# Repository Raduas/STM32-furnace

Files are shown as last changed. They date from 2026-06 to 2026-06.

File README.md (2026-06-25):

# STM32 Induction Furnace

A personal project focused on designing and building a resonant H-bridge induction furnace controlled by an STM32 microcontroller.

This was my first larger electronics project and gave me hands-on experience with power electronics, control systems, PCB design, and embedded software development.

The furnace was not completed as a final product, but core functionality was successfully tested. Maximum achieved temperature reached the Curie point.

# Challenges
Learning the fundamentals of power electronics.
Understanding resonant circuits and H-bridge operation.
Designing reliable gate driver circuits.
Managing electrical noise and ground isolation.
Debugging hardware and software interactions.
Developing and tuning control algorithms.

# Lessons Learned

Through this project, I gained practical experience in:

Power electronics design.
Designing power supplies with multiple voltage levels.
STM32 development using STM32CubeIDE.
Implementing control algorithms for an H-bridge inverter.
Applying Ohm's Law and basic circuit analysis in real-world situations.
Reading and understanding component datasheets.
PCB design, including gate driver layout and ground isolation.
Using laboratory equipment such as oscilloscopes and multimeters.
System debugging and troubleshooting.

## PCB Design

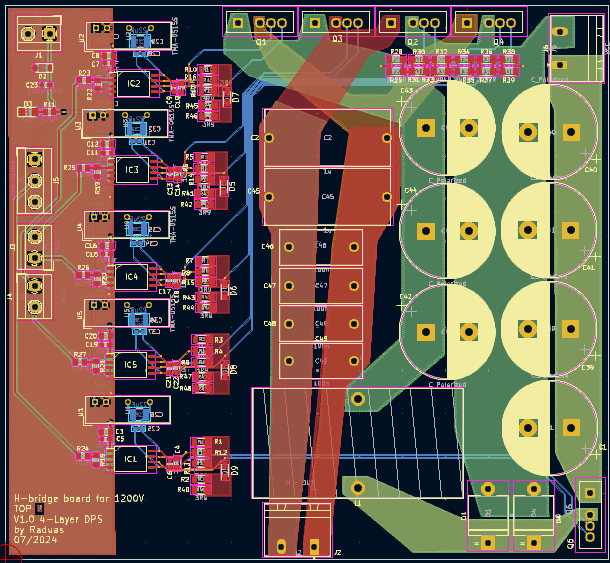
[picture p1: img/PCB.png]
PCB


## Schematic

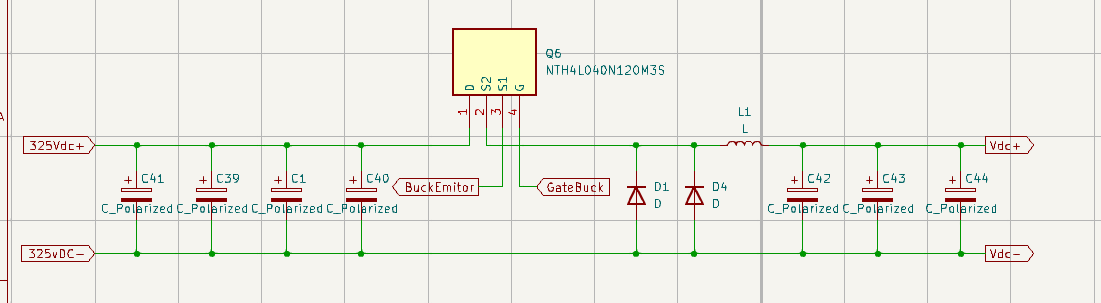
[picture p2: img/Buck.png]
Buck

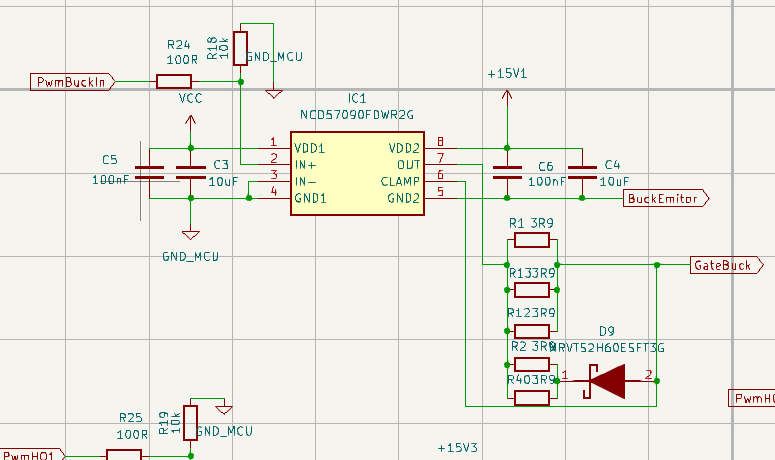
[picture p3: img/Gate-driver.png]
Gate Driver

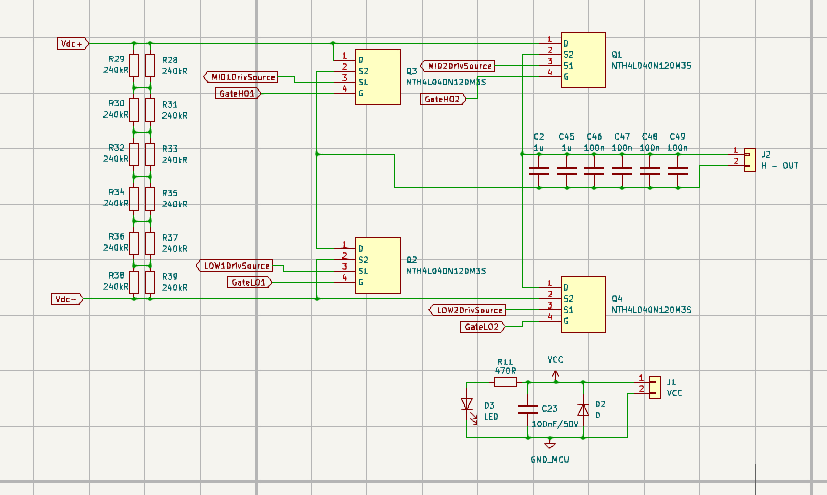
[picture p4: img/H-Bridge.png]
H-Bridge


## Assebled PCB

Assebled PCB

# Future Improvements

If I were to redesign the system today, I would:

Improve thermal management and cooling.
Reconsider the overall system architecture.
Spend more time on mathematical analysis before implementation.
Perform more simulations and design reviews early in development.
Add additional protection features and fault detection mechanisms.
Improve PCB layout to reduce noise and simplify debugging.

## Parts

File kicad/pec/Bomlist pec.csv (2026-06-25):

'Reference' | 'Value' | 'Datasheet' | 'Footprint' | 'Qty' | 'DNP'
'C1,C39,C40,C41,C42,C43,C44' | 'C_Polarized' | '~' | 'Capacitor_THT:CP_Radial_D22.0mm_P10.00mm_SnapIn' | '7' | ''
'C2,C45' | '1u' | '~' | 'Capacitor_THT:C_Rect_L29.0mm_W13.0mm_P27.50mm_MKT' | '2' | ''
'C3,C4,C8,C10,C12,C14,C16,C18,C20,C22' | '10uF' | '~' | 'Capacitor_SMD:C_0805_2012Metric_Pad1.18x1.45mm_HandSolder' | '10' | ''
'C5,C6,C7,C9,C11,C13,C15,C17,C19,C21,C24,C25,C27,C28,C30,C31,C33,C34,C36,C37' | '100nF' | '~' | 'Capacitor_SMD:C_0603_1608Metric_Pad1.08x0.95mm_HandSolder' | '20' | ''
'C23' | '100nF/50V' | '~' | 'Capacitor_SMD:C_0603_1608Metric_Pad1.08x0.95mm_HandSolder' | '1' | ''
'C26,C29,C32,C35,C38' | '22uF' | '~' | 'Capacitor_SMD:C_1210_3225Metric_Pad1.33x2.70mm_HandSolder' | '5' | ''
'C46,C47,C48,C49' | '100n' | '~' | 'Capacitor_THT:C_Rect_L19.0mm_W8.0mm_P15.00mm_MKS4' | '4' | ''
'D1,D2,D4' | 'D' | '~' | '-- mixed values --' | '3' | ''
'D3' | 'LED' | '~' | 'LED_SMD:LED_1206_3216Metric_Pad1.42x1.75mm_HandSolder' | '1' | ''
'D5,D6,D7,D8,D9' | 'NRVTS2H60ESFT3G' | 'https://www.onsemi.com/pub/Collateral/NRVTS2H60ESF-D.PDF' | 'SODFL3616X98N' | '5' | ''
'IC1,IC2,IC3,IC4,IC5' | 'NCD57090FDWR2G' | 'https://www.onsemi.com/pub/Collateral/NCD57090A-D.PDF' | 'SOIC127P1031X265-8N' | '5' | ''
'J1,J3,J4,J6' | 'VCC' | '~' | '-- mixed values --' | '4' | ''
'J2' | 'H - OUT' | '~' | 'Connector_Phoenix_GMSTB:PhoenixContact_GMSTBA_2,5_2-G-7,62_1x02_P7.62mm_Horizontal' | '1' | ''
'J5' | 'Conn_01x03' | '~' | 'TerminalBlock_MetzConnect:TerminalBlock_MetzConnect_Type055_RT01503HDWU_1x03_P5.00mm_Horizontal' | '1' | ''
'L1' | 'L' | '~' | 'Inductor_THT:L_Toroid_Vertical_L48.8mm_W25.4mm_P20.80mm_Vishay_TJ8' | '1' | ''
'Q1,Q2,Q3,Q4,Q6' | 'NTH4L040N120M3S' | 'https://www.onsemi.com/pub/Collateral/NTH4L040N120M3S-D.PDF' | 'NTH4L040N120M3S' | '5' | ''
'R1,R2,R3,R4,R5,R6,R7,R8,R9,R10,R12,R13,R14,R15,R16,R17,R40,R41,R42,R43,R44,R45,R46,R47,R48' | '3R9' | '~' | 'Resistor_SMD:R_1206_3216Metric_Pad1.30x1.75mm_HandSolder' | '25' | ''
'R11' | '470R' | '~' | 'Resistor_SMD:R_0805_2012Metric_Pad1.20x1.40mm_HandSolder' | '1' | ''
'R18,R19,R20,R21,R22' | '10k' | '~' | 'Resistor_SMD:R_0805_2012Metric_Pad1.20x1.40mm_HandSolder' | '5' | ''
'R23,R24,R25,R26,R27' | '100R' | '~' | 'Resistor_SMD:R_0805_2012Metric_Pad1.20x1.40mm_HandSolder' | '5' | ''
'R28,R29,R30,R31,R32,R33,R34,R35,R36,R37,R38,R39' | '240kR' | '~' | 'Resistor_SMD:R_1206_3216Metric_Pad1.30x1.75mm_HandSolder' | '12' | ''
'U1,U2,U3,U4,U5' | 'TMA-0515S' | 'https://www.tracopower.com/products/tma.pdf' | 'Converter_DCDC:Converter_DCDC_TRACO_TMA-05xxS_12xxS_Single_THT' | '5' | ''

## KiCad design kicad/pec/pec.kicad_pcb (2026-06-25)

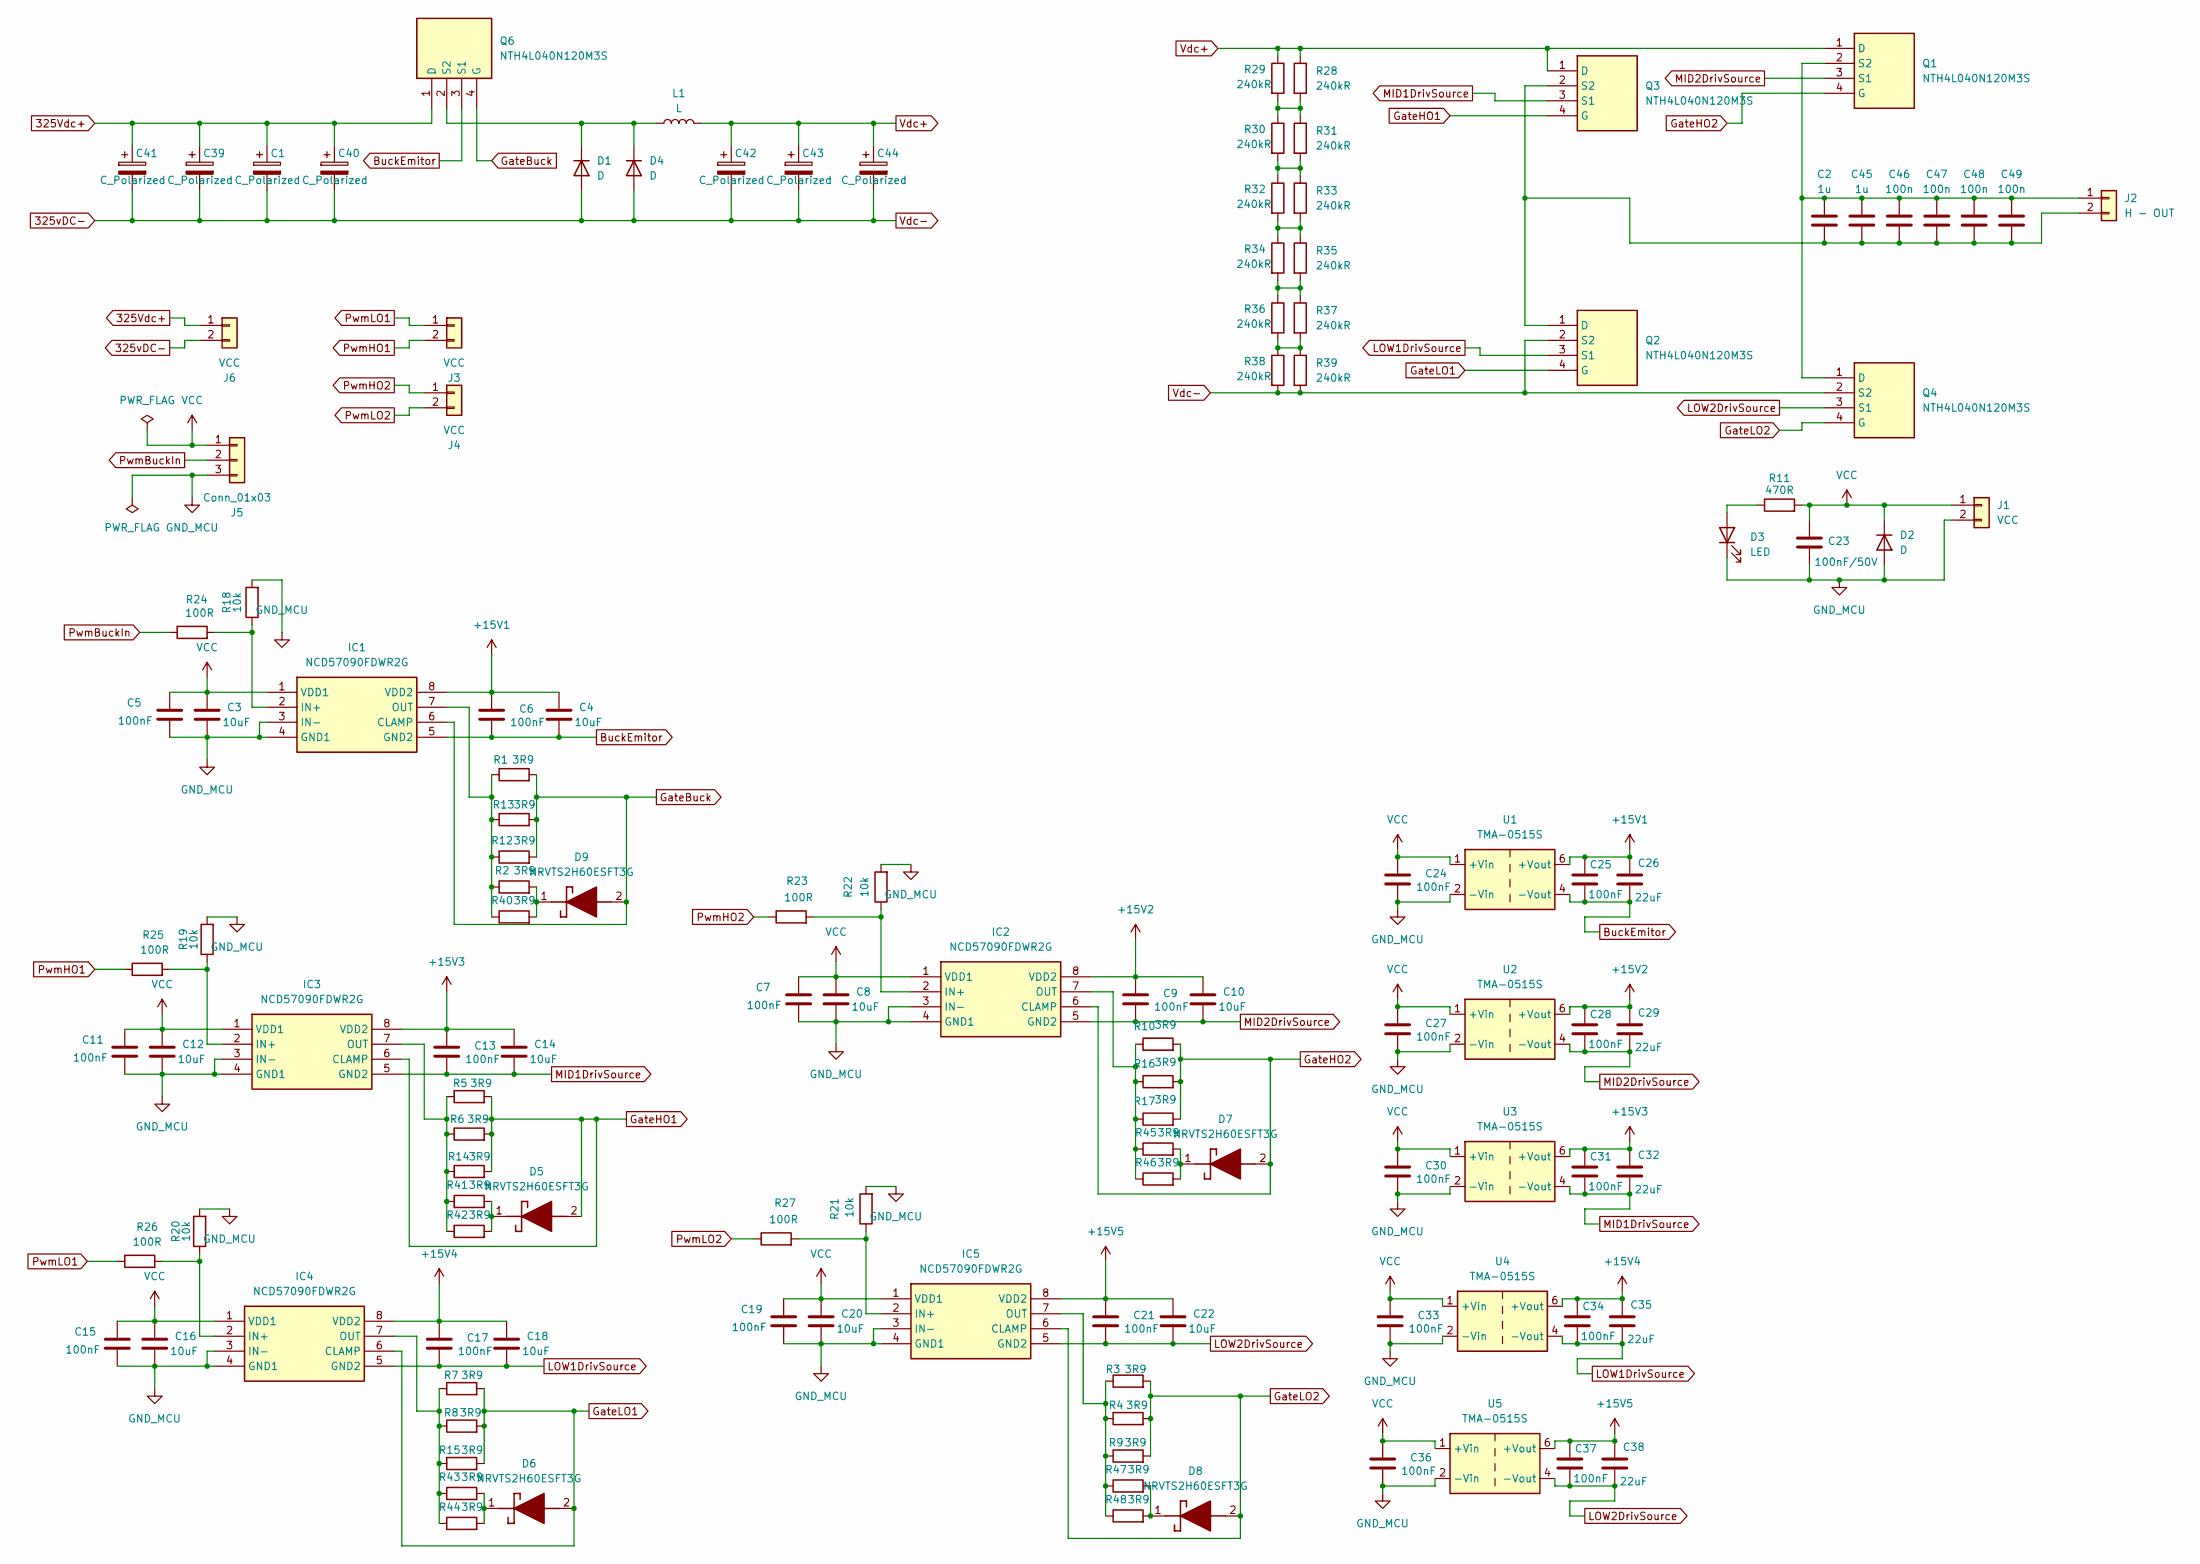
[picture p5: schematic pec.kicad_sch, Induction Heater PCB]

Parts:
C1, C39, C40, C41, C42, C43, C44: C_Polarized; CP_Radial_D22.0mm_P10.00mm_SnapIn
C2, C45: 1u; C_Rect_L29.0mm_W13.0mm_P27.50mm_MKT
C3, C4, C8, C10, C12, C14, C16, C18, C20, C22: 10uF; C_0805_2012Metric_Pad1.18x1.45mm_HandSolder
C5, C6, C7, C9, C11, C13, C15, C17, C19, C21, C24, C25, C27, C28, C30, C31, C33, C34, C36, C37: 100nF; C_0603_1608Metric_Pad1.08x0.95mm_HandSolder
C23: 100nF/50V; C_0603_1608Metric_Pad1.08x0.95mm_HandSolder
C26, C29, C32, C35, C38: 22uF; C_1210_3225Metric_Pad1.33x2.70mm_HandSolder
C46, C47, C48, C49: 100n; C_Rect_L19.0mm_W8.0mm_P15.00mm_MKS4
D1, D4: D; D_P600_R-6_P12.70mm_Horizontal
D2: D; D_SOD-123
D3: LED; LED_1206_3216Metric_Pad1.42x1.75mm_HandSolder
D5, D6, D7, D8, D9: NRVTS2H60ESFT3G; SODFL3616X98N; Manufacturer_Part_Number NRVTS2H60ESFT3G; Mouser Part Number 863-NRVTS2H60ESFT3G
IC1, IC2, IC3, IC4, IC5: NCD57090FDWR2G; SOIC127P1031X265-8N; Manufacturer_Part_Number NCD57090FDWR2G; Mouser Part Number 863-NCD57090FDWR2G
J1, J3, J4: VCC; TerminalBlock_MetzConnect_Type055_RT01502HDWU_1x02_P5.00mm_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
J2: H - OUT; PhoenixContact_GMSTBA_2,5_2-G-7,62_1x02_P7.62mm_Horizontal
J5: Conn_01x03; TerminalBlock_MetzConnect_Type055_RT01503HDWU_1x03_P5.00mm_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
J6: VCC; PhoenixContact_GMSTBA_2,5_2-G-7,62_1x02_P7.62mm_Horizontal
L1: L; L_Toroid_Vertical_L48.8mm_W25.4mm_P20.80mm_Vishay_TJ8
Q1, Q2, Q3, Q4, Q6: NTH4L040N120M3S; Manufacturer_Part_Number NTH4L040N120M3S; Mouser Part Number 863-NTH4L040N120M3S
R1, R2, R3, R4, R5, R6, R7, R8, R9, R10, R12, R13, R14, R15, R16, R17, R40, R41, R42, R43, R44, R45, R46, R47, R48: 3R9; R_1206_3216Metric_Pad1.30x1.75mm_HandSolder
R11: 470R; R_0805_2012Metric_Pad1.20x1.40mm_HandSolder
R18, R19, R20, R21, R22: 10k; R_0805_2012Metric_Pad1.20x1.40mm_HandSolder
R23, R24, R25, R26, R27: 100R; R_0805_2012Metric_Pad1.20x1.40mm_HandSolder
R28, R29, R30, R31, R32, R33, R34, R35, R36, R37, R38, R39: 240kR; R_1206_3216Metric_Pad1.30x1.75mm_HandSolder
U1, U2, U3, U4, U5: TMA-0515S; Converter_DCDC_TRACO_TMA-05xxS_12xxS_Single_THT

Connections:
325Vdc+: C1.1, C39.1, C40.1, C41.1, J6.1, Q6.1 (D)
325vDC-: C1.2, C39.2, C40.2, C41.2, C42.2, C43.2, C44.2, D1.2 (A), D4.2 (A), J6.2, Q2.2 (S2), Q4.2 (S2), R38.2, R39.2
+15V1: C4.2, C6.2, C25.2, C26.2, IC1.8 (VDD2), U1.6 (+Vout)
+15V2: C9.2, C10.2, C28.2, C29.2, IC2.8 (VDD2), U2.6 (+Vout)
+15V3: C13.2, C14.2, C31.2, C32.2, IC3.8 (VDD2), U3.6 (+Vout)
+15V4: C17.2, C18.2, C34.2, C35.2, IC4.8 (VDD2), U4.6 (+Vout)
+15V5: C21.2, C22.2, C37.2, C38.2, IC5.8 (VDD2), U5.6 (+Vout)
BuckEmitor: C4.1, C6.1, C25.1, C26.1, IC1.5 (GND2), Q6.3 (S1), U1.4 (-Vout)
GND_MCU: C3.1, C5.1, C7.1, C8.1, C11.1, C12.1, C15.1, C16.1, C19.1, C20.1, C23.1, C24.1, C27.1, C30.1, C33.1, C36.1, D2.2 (A), D3.1 (K), IC1.3 (IN-), IC1.4 (GND1), IC2.3 (IN-), IC2.4 (GND1), IC3.3 (IN-), IC3.4 (GND1), IC4.3 (IN-), IC4.4 (GND1), IC5.3 (IN-), IC5.4 (GND1), J1.2, J5.3, R18.2, R19.2, R20.2, R21.2, R22.2, U1.2 (-Vin), U2.2 (-Vin), U3.2 (-Vin), U4.2 (-Vin), U5.2 (-Vin)
GateBuck: D9.2 (A), IC1.6 (CLAMP), Q6.4 (G), R1.2, R12.2, R13.2
GateHO1: D5.2 (A), IC3.6 (CLAMP), Q3.4 (G), R5.2, R6.2, R14.2
GateHO2: D7.2 (A), IC2.6 (CLAMP), Q1.4 (G), R10.2, R16.2, R17.2
GateLO1: D6.2 (A), IC4.6 (CLAMP), Q2.4 (G), R7.2, R8.2, R15.2
GateLO2: D8.2 (A), IC5.6 (CLAMP), Q4.4 (G), R3.2, R4.2, R9.2
LOW1DrivSource: C17.1, C18.1, C34.1, C35.1, IC4.5 (GND2), Q2.3 (S1), U4.4 (-Vout)
LOW2DrivSource: C21.1, C22.1, C37.1, C38.1, IC5.5 (GND2), Q4.3 (S1), U5.4 (-Vout)
MID1DrivSource: C13.1, C14.1, C31.1, C32.1, IC3.5 (GND2), Q3.3 (S1), U3.4 (-Vout)
MID2DrivSource: C9.1, C10.1, C28.1, C29.1, IC2.5 (GND2), Q1.3 (S1), U2.4 (-Vout)
unnamed: D1.1 (K), D4.1 (K), L1.1, Q6.2 (S2)
unnamed: D3.2 (A), R11.1
unnamed: D5.1 (K), R41.2, R42.2
unnamed: D6.1 (K), R43.2, R44.2
unnamed: D7.1 (K), R45.2, R46.2
unnamed: D8.1 (K), R47.2, R48.2
unnamed: D9.1 (K), R2.2, R40.2
unnamed: IC1.2 (IN+), R18.1, R24.2
unnamed: IC1.7 (OUT), R1.1, R2.1, R12.1, R13.1, R40.1
unnamed: IC2.2 (IN+), R22.1, R23.2
unnamed: IC2.7 (OUT), R10.1, R16.1, R17.1, R45.1, R46.1
unnamed: IC3.2 (IN+), R19.1, R25.2
unnamed: IC3.7 (OUT), R5.1, R6.1, R14.1, R41.1, R42.1
unnamed: IC4.2 (IN+), R20.1, R26.2
unnamed: IC4.7 (OUT), R7.1, R8.1, R15.1, R43.1, R44.1
unnamed: IC5.2 (IN+), R21.1, R27.2
unnamed: IC5.7 (OUT), R3.1, R4.1, R9.1, R47.1, R48.1
unnamed: C2.2, C45.2, C46.2, C47.2, C48.2, C49.2, J2.1, Q1.2 (S2), Q4.1 (D)
unnamed: C2.1, C45.1, C46.1, C47.1, C48.1, C49.1, J2.2, Q2.1 (D), Q3.2 (S2)
unnamed: R28.2, R29.2, R30.1, R31.1
unnamed: R30.2, R31.2, R32.1, R33.1
unnamed: R32.2, R33.2, R34.1, R35.1
unnamed: R34.2, R35.2, R36.1, R37.1
unnamed: R36.2, R37.2, R38.1, R39.1
PwmBuckIn: J5.2, R24.1
PwmHO1: J3.2, R25.1
PwmHO2: J4.1, R23.1
PwmLO1: J3.1, R26.1
PwmLO2: J4.2, R27.1
VCC: C3.2, C5.2, C7.2, C8.2, C11.2, C12.2, C15.2, C16.2, C19.2, C20.2, C23.2, C24.2, C27.2, C30.2, C33.2, C36.2, D2.1 (K), IC1.1 (VDD1), IC2.1 (VDD1), IC3.1 (VDD1), IC4.1 (VDD1), IC5.1 (VDD1), J1.1, J5.1, R11.2, U1.1 (+Vin), U2.1 (+Vin), U3.1 (+Vin), U4.1 (+Vin), U5.1 (+Vin)
Vdc+: C42.1, C43.1, C44.1, L1.2, Q1.1 (D), Q3.1 (D), R28.1, R29.1

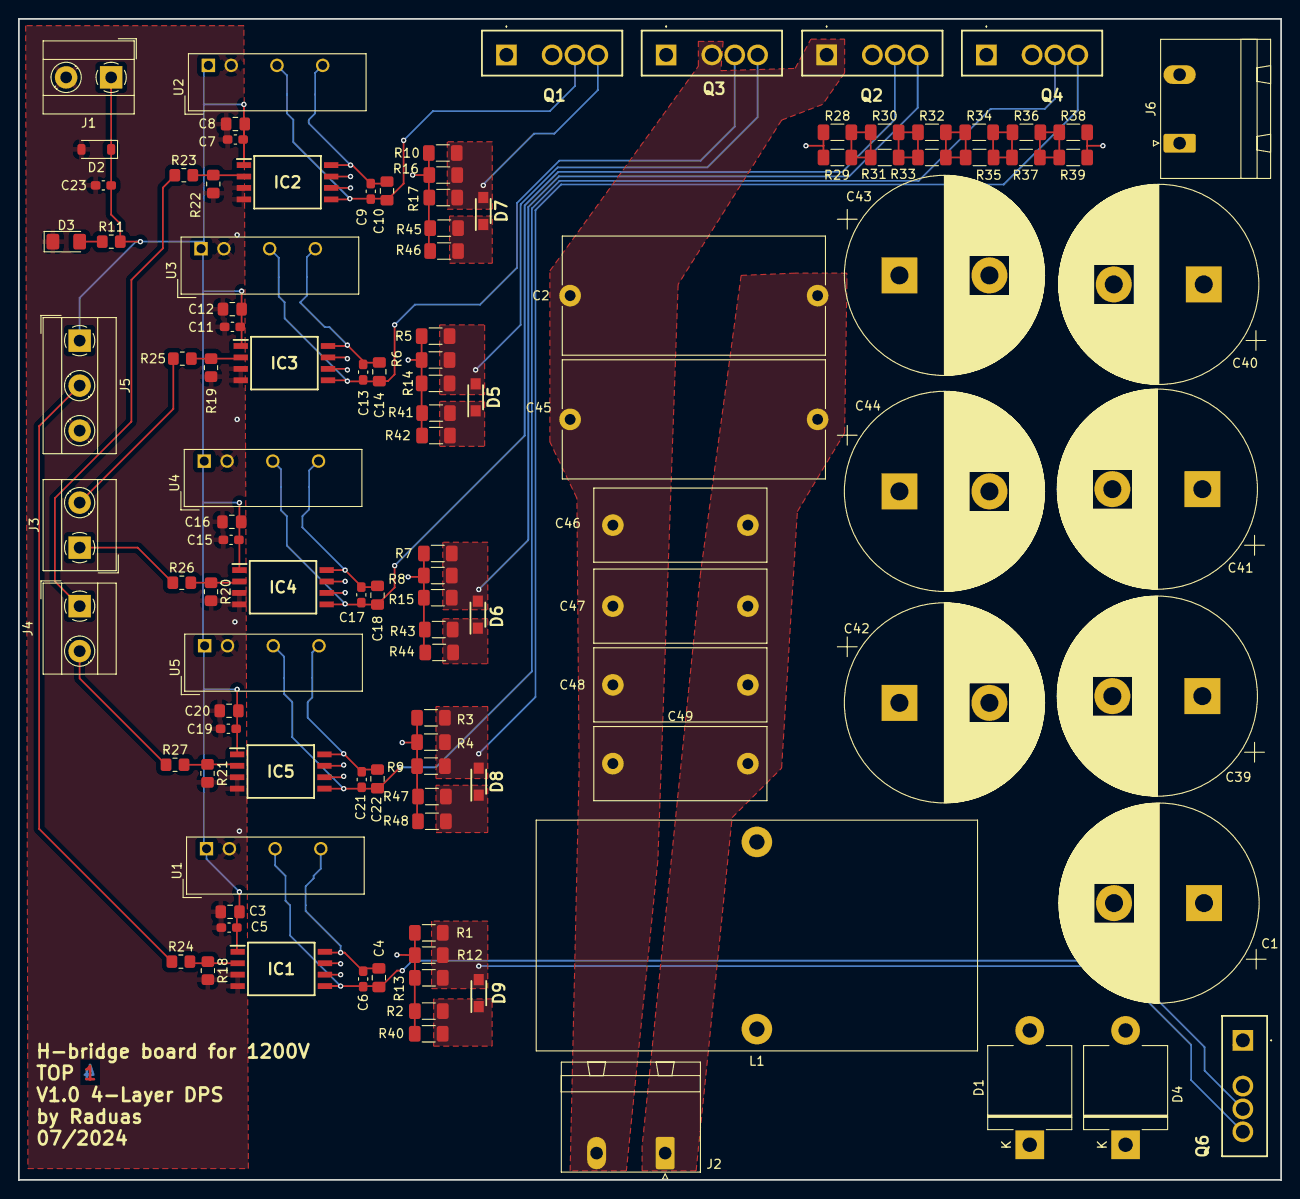
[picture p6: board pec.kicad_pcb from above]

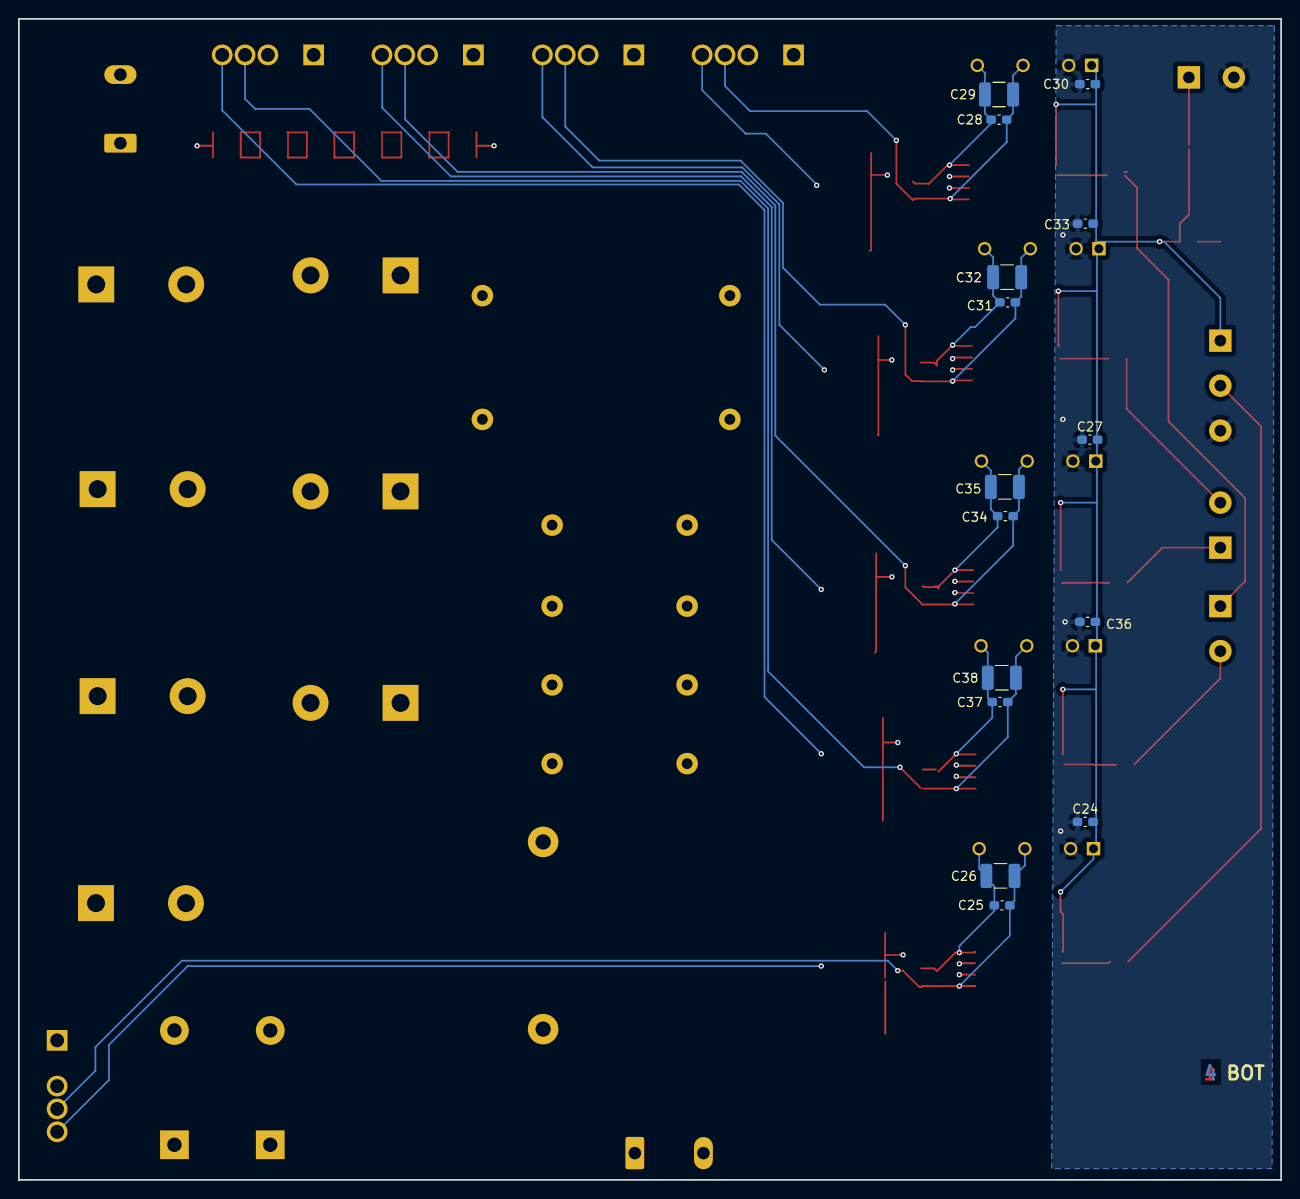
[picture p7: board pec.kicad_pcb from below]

Board: 4 copper layers, 140.2 x 129.0 mm, 128 parts (15 on the bottom side), 49 nets.

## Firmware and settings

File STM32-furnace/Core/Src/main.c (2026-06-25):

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
/* Includes ------------------------------------------------------------------*/
#include "main.h"

/* USER CODE BEGIN Includes */
#include "wcs1700float.h"
#include "base_funtions.h"
#include "stdio.h" //printf funkce
#include <math.h>
#include "i2c_lcd.h"
/* USER CODE END Includes */

ADC_HandleTypeDef hadc1;
ADC_HandleTypeDef hadc2;

I2C_HandleTypeDef hi2c1;

TIM_HandleTypeDef htim1;
TIM_HandleTypeDef htim3;
TIM_HandleTypeDef htim7;
TIM_HandleTypeDef htim8;

UART_HandleTypeDef huart2;

/* USER CODE BEGIN PV */
/* USER CODE BEGIN PV */
I2C_LCD_HandleTypeDef lcd1;
/* USER CODE END PV */

void SystemClock_Config(void);
static void MX_GPIO_Init(void);
static void MX_USART2_UART_Init(void);
static void MX_TIM1_Init(void);
static void MX_ADC1_Init(void);
static void MX_TIM3_Init(void);
static void MX_TIM8_Init(void);
static void MX_TIM7_Init(void);
static void MX_I2C1_Init(void);
static void MX_ADC2_Init(void);
/* USER CODE BEGIN 0 */
int F;
int G=0;
float current_mA;
float f_current_mV;
float setpoint_mA = 5;    // požadovaný proud v mA
float pwm_duty = 0.0f;

float Kp = 0.001f, Ki = 0.01f, Kd = 10.0f;
float integral = 0, last_error = 0;

float PID_Compute(float setpoint, float measured);
//test
float duty;

uint32_t lastCalibrationTick = 0;
uint8_t b_pwmOn = 0;
uint32_t lastmeasure;

/* USER CODE END 0 */

/**
  * @brief  The application entry point.
  * @retval int
  */
int main(void)
{

  /* MCU Configuration--------------------------------------------------------*/

  /* Reset of all peripherals, Initializes the Flash interface and the Systick. */
  HAL_Init();

  /* Configure the system clock */
  SystemClock_Config();

  /* Initialize all configured peripherals */
  MX_GPIO_Init();
  MX_USART2_UART_Init();
  MX_TIM1_Init();
  MX_ADC1_Init();
  MX_TIM3_Init();
  MX_TIM8_Init();
  MX_TIM7_Init();
  MX_I2C1_Init();
  MX_ADC2_Init();
  /* USER CODE BEGIN 2 */
  lcd1.address = (0x27 << 1);   // typická adresa I2C expanderu PCF8574, někdy 0x3F
  lcd1.hi2c = &hi2c1;        // propojení s tvým I2C handlerem
  lcd_init(&lcd1);           // inicializace LCD
  lcd_clear(&lcd1);          // vyčisti displej
  lcd_puts(&lcd1, "Init OK"); // test
  //WCS1700float_Init(&hadc1);
  //HAL_ADC_Start(&hadc1);
  HAL_Delay(1000);
  //WCS1700float_Calibrate();
  HAL_Delay(1000);
  allPWMStart();
  /* USER CODE END 2 */

  /* Infinite loop */
  /* USER CODE BEGIN WHILE */
  while (1)
  {
    /* USER CODE END WHILE */

    /* USER CODE BEGIN 3 */

	  	GPIO_PinState sw = HAL_GPIO_ReadPin(Start_GPIO_Port, Start_Pin);

	  	if (sw == GPIO_PIN_SET && b_pwmOn == 0) {
	  		allPWMStart();
	  		b_pwmOn = 1;
	  	}
	  	else if (sw == GPIO_PIN_RESET && b_pwmOn == 1) {
	  		allPWMStop();
	  	   b_pwmOn = 0;
	  	   lcd_clear(&lcd1);
	  	   lcd_puts(&lcd1, "Stopped");
	  	}
	  	if (b_pwmOn == 1) {
	  		lcd_clear(&lcd1);
	  		char buffer[16];
	  		int intAPart = (int)current_mA;
	  		int fracAPart = (int)((current_mA - intAPart) * 10); // 1 desetinná místa
	  		int intPWMPart = (int)pwm_duty;
	  		sprintf(buffer, "Run A:%d.%01d PWM:%d",intAPart, fracAPart,intPWMPart);

	  		lcd_puts(&lcd1, buffer);
	  		lcd_gotoxy(&lcd1, 0, 1);

	  		int intNPart = (int)calibrationConstant_mV;
	  		int fracNPart = (int)((calibrationConstant_mV - intNPart) * 10);

	  		int intCPart = (int)f_current_mV;
	  		int fracCPart = (int)((f_current_mV - intCPart) * 10);

	  		sprintf(buffer, "N:%d C:%d",
	  		        intNPart,
	  		        intCPart);
	  		lcd_puts(&lcd1, buffer);
	  	}
	  	HAL_Delay(100);

  }
  /* USER CODE END 3 */
}

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
/* USER CODE BEGIN 4 */
void setFreqHBridge(float freq)
{
	  if (freq==0)
	  {
		__HAL_TIM_DISABLE(&htim1);
	    Error_Handler();
	  }
	  uint32_t arr = (uint32_t)((10000000.0f / freq) - 1.0f);

	  __HAL_TIM_DISABLE(&htim1);
	  __HAL_TIM_SET_AUTORELOAD(&htim1, arr);
	  __HAL_TIM_SET_COMPARE(&htim1, TIM_CHANNEL_1, arr / 2); // 50% duty
	  __HAL_TIM_SET_COMPARE(&htim1, TIM_CHANNEL_2, arr / 2); // 50% duty
	  __HAL_TIM_ENABLE(&htim1);
}


float PID_Compute(float setpoint, float measured)
{
    float error = setpoint - measured;
    integral += error;
    if (integral > 11000.0f) integral = 11000.0f;
    if (integral < 0.0f) integral = 0.0f;
    float derivative = error - last_error;
    last_error = error;

    float output = Kp * error + Ki * integral + Kd * derivative;

    // Saturace výstupu 0–100 %
    if (output > 100.0f) output = 100.0f;
    if (output < 0.0f) output = 0.0f;

    return output;
}
void HAL_TIM_PeriodElapsedCallback(TIM_HandleTypeDef *htim)
{
    if (htim->Instance == TIM7)//10kHz
    {
    	//ReadCurrent_Flow(&f_current_mV);

    	/*
    	duty = (float)__HAL_TIM_GET_COMPARE(&htim3, TIM_CHANNEL_1) / __HAL_TIM_GET_AUTORELOAD(&htim3);
float f_Vout = 325.0f * duty;float R_load = 22.0f; current_mA = f_Vout / R_load; */
    }
    if (htim->Instance == TIM8) //1kHz
    {
   	/*current_mA = frommV2A(&f_current_mV);
    	pwm_duty = PID_Compute(setpoint_mA, current_mA);
    	uint32_t pwm_value = (uint32_t)((pwm_duty / 100.0f) * __HAL_TIM_GET_AUTORELOAD(&htim3)); // mapování % na hodnotu TIM3->CCR1*/
    	__HAL_TIM_SET_COMPARE(&htim3, TIM_CHANNEL_1, 49); //pwm_value/4
    }

}
/* USER CODE END 4 */
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


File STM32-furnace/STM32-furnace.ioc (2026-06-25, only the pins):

Mcu.UserName=STM32F446RETx
PA1.Signal=ADCx_IN1
PA13.GPIO_Label=TMS
PA13.Signal=SYS_JTMS-SWDIO
PA14.GPIO_Label=TCK
PA14.Signal=SYS_JTCK-SWCLK
PA2.GPIO_Label=USART_TX
PA2.Signal=USART2_TX
PA3.GPIO_Label=USART_RX
PA3.Signal=USART2_RX
PA5.GPIO_Label=LD2 [Green Led]
PA5.Signal=GPIO_Output
PA7.GPIO_Label=Start
PA7.Signal=GPIO_Input
PA8.GPIO_Label=HighA
PA8.Signal=S_TIM1_CH1
PA9.GPIO_Label=HighB
PA9.Signal=S_TIM1_CH2
PB0.Signal=ADCx_IN8
PB13.GPIO_Label=LowA
PB13.Signal=TIM1_CH1N
PB14.GPIO_Label=LowB
PB14.Signal=TIM1_CH2N
PB3.GPIO_Label=SWO
PB3.Signal=SYS_JTDO-SWO
PB4.GPIO_Label=Buck
PB4.Signal=S_TIM3_CH1
PB8.Signal=I2C1_SCL
PB9.Signal=I2C1_SDA
PC13.GPIO_Label=B1 [Blue PushButton]
PC13.Signal=GPXTI13
PC14-OSC32_IN.Signal=RCC_OSC32_IN
PC15-OSC32_OUT.Signal=RCC_OSC32_OUT
PH0-OSC_IN.Signal=RCC_OSC_IN
PH1-OSC_OUT.Signal=RCC_OSC_OUT

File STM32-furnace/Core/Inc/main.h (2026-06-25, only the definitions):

#define B1_Pin GPIO_PIN_13
#define B1_GPIO_Port GPIOC
#define USART_TX_Pin GPIO_PIN_2
#define USART_TX_GPIO_Port GPIOA
#define USART_RX_Pin GPIO_PIN_3
#define USART_RX_GPIO_Port GPIOA
#define LD2_Pin GPIO_PIN_5
#define LD2_GPIO_Port GPIOA
#define Start_Pin GPIO_PIN_7
#define Start_GPIO_Port GPIOA
#define LowA_Pin GPIO_PIN_13
#define LowA_GPIO_Port GPIOB
#define LowB_Pin GPIO_PIN_14
#define LowB_GPIO_Port GPIOB
#define HighA_Pin GPIO_PIN_8
#define HighA_GPIO_Port GPIOA
#define HighB_Pin GPIO_PIN_9
#define HighB_GPIO_Port GPIOA
#define TMS_Pin GPIO_PIN_13
#define TMS_GPIO_Port GPIOA
#define TCK_Pin GPIO_PIN_14
#define TCK_GPIO_Port GPIOA
#define SWO_Pin GPIO_PIN_3
#define SWO_GPIO_Port GPIOB
#define Buck_Pin GPIO_PIN_4
#define Buck_GPIO_Port GPIOB

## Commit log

2026-06-25 full project to git
    [Bomlist pec.csv, mereni.kicad_sch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]
2026-06-25 Revise README with detailed project overview
    Expanded project description and added sections on challenges, lessons learned, PCB design, and future improvements.
2026-06-25 Update PCB image format from JPG to PNG

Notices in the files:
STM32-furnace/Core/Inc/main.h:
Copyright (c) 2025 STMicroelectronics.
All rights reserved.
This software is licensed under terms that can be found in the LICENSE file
